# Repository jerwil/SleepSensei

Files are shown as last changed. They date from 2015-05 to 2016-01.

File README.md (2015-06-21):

# The Sleep Sensei

A device to help users fall asleep using calming breathing training.

Sleep Sensei Logo

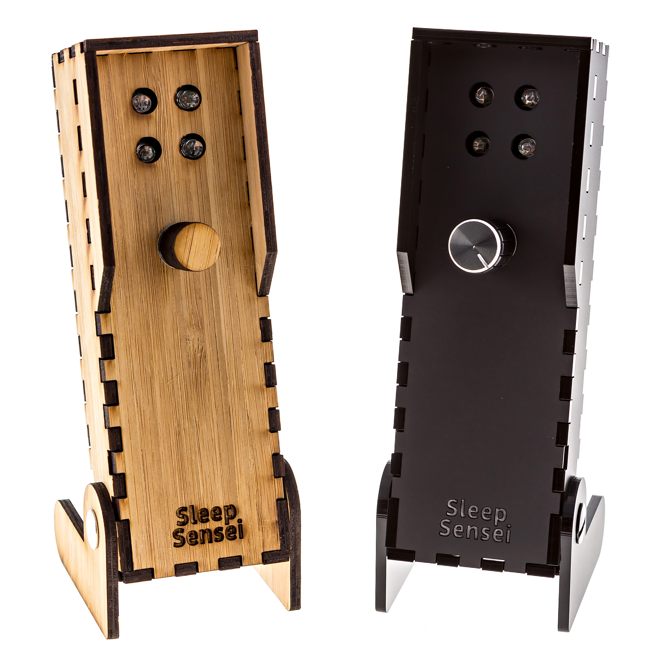
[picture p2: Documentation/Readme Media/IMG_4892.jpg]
Sleep Sensei Photos


## Features

* Creates a pattern of light that you match your breathing to
* Breathing rate is decreased during coaching session, so this helps ease you into sleep faster
* The maximum brightness can be adjusted on-the-fly
* 4 built-in profiles
* The initial breath length, final breath length, and session duration are adjustable for all 4 profiles
* Profile modifications are saved to the device's non-volatile memory
* One-button/knob operation

## How to Use

* Set up the Sleep Sensei on a night stand or table next to your bed.
* Turn on the sleep coach and adjust its angle to either shine in your eyes or on a wall or ceiling.
* Chose a profile and start a sleep coaching session
* Follow the pattern of light with your breathing (brighter = inhale, dimmer = exhale)
* Fall asleep faster!

## Kickstarter

The Sleep Sensei is on Kickstarter!

* [Kickstarter Link](https://www.kickstarter.com/projects/1999114877/the-sleep-sensei)

## Study

I have been conducting a study to collect data on the Sleep Coach to see if it actually helps users fall asleep.

* [Study Information](http://i.imgur.com/wzw9Kvx.jpg)
* [Study Sign-up link] (http://goo.gl/noJXXP)
* [Study Results So Far] (https://github.com/jerwil/SleepCoach/blob/master/Documentation/Data%20Summary%20-%20Round%202.pdf?raw=true)

So far I have had great success with the Sleep Sensei. I'm always looking for more study participants!

## Requirements

### Hardware

* ATtiny85
* 8 pin DIP socket (recommended)
* 220Ω resistor
* 2 10kΩ resistors
* 10 mF capacitor
* 4 red LEDs
* Rotary encoder
* Battery holder for 2 AA batteries
* Body/housing (lasercut design included in repository)

### Schematics

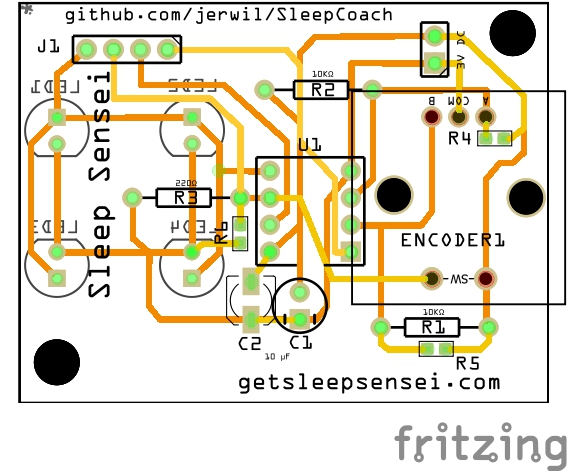
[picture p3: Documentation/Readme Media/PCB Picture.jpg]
Sleep Coach schematic


See the included Fritzing diagram (.fzz file) for details.

### License

<br /><span xmlns:dct="http://purl.org/dc/terms/" property="dct:title">Sleep Sensei</span> by <a xmlns:cc="http://creativecommons.org/ns#" href="http://www.JeremyAdamWilson.com">Jeremy Wilson</a> is licensed under a <a rel="license" href="http://creativecommons.org/licenses/by-nc/4.0/">Creative Commons Attribution-NonCommercial 4.0 International License</a>.

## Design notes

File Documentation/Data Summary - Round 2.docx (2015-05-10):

Sleep Coach Study – Round 2 Results

Study Premise: I created a device to try to help people fall asleep faster. I found several people willing to try the device and provide me data on their sleep via a daily survey and seep tracking smartphone app. I had the users record data for 3 weeks without the sleep coach, and I then sent the users the sleep coach device and had them record data for 3 weeks of sleep using the device.

Device Details: The Arduino-based device produces adjustable high-intensity light that can shine through your eyelids in a sinusoidally increasing and decreasing pattern of brightness with a period that lengthens over time. You match your breathing up with the intensity of the light, and over time your breathing slows.

The big problem I found with similar smartphone apps is that you need to have your eyes open to see the light, and most people do not try to get to sleep with their eyes open. I’ve designed the device to be adjustable to obtain the ideal angle of light from the nightstand to the eyes, and the max brightness is adjustable. The device is in an alpha state, meaning it isn’t pretty, but it gets the job done.

Results

User 1:

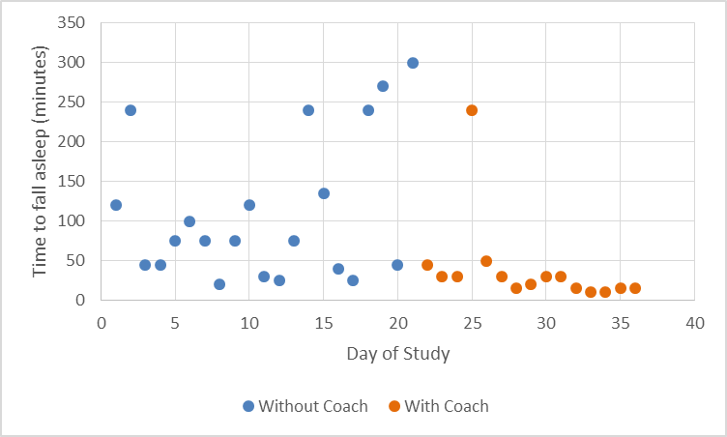
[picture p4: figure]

Average time to sleep without sleep coach: 111 minutes.

Average time to sleep with sleep coach: 39 minutes (25 minutes with outlier removed).

User Thoughts: “I think the quality of sleep has been improving, and I think that's the sleep coach.”

User 2:

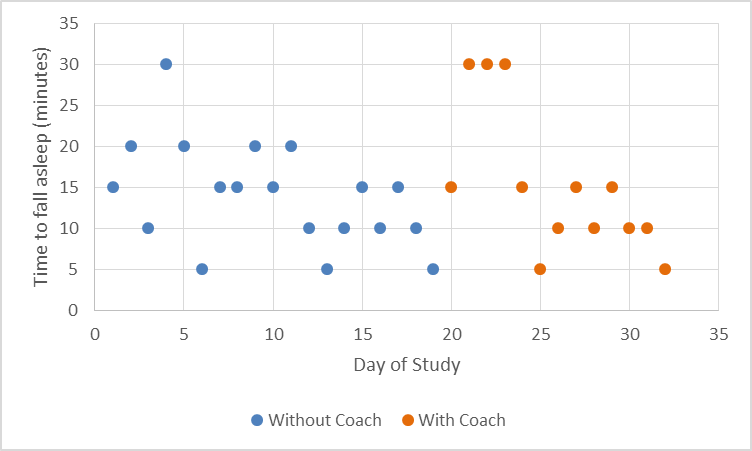
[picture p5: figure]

Average time to sleep without sleep coach: 21 minutes (14 minutes with outlier removed).

Average time to sleep with sleep coach: 15 minutes.

User Thoughts: “I was really impressed with the sleep coach- it cut the amount of time it took me to fall asleep by about half.”

User 3:

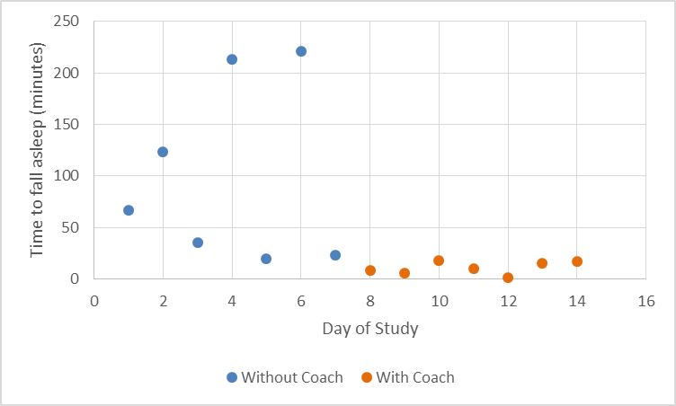
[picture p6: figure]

Average time to sleep without sleep coach: 100 minutes

Average time to sleep with sleep coach: 11 minutes.

Note: this user only provided 2 weeks of data.

New user data as of 5/25/13:

User 4:

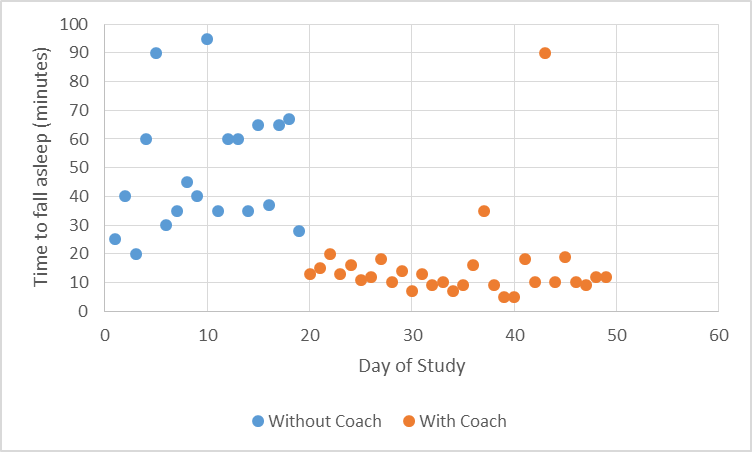
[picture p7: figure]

Average time to sleep without sleep coach: 49 minutes

Average time to sleep with sleep coach: 15 minutes (12 minutes with outlier removed).

User Thoughts: “When I am able to settle down and get in bed at a decent hour, the sleep coach helps immensely in allowing me to fall asleep in an acceptable amount of time. Usually I get incredibly distracted and it can take an hour, sometimes many hours, to fall asleep. The sleep coach allows me to fall asleep in at least under 30 minutes, sometimes even as few as 7 minutes, which is great for me! I would definitely recommend this device to anyone who is on the search for something new to help them fall asleep, someone who perhaps has tried every other sleep aid without finding anything that truly helps yet. The Sleep Coach is awesome!”

User 5:

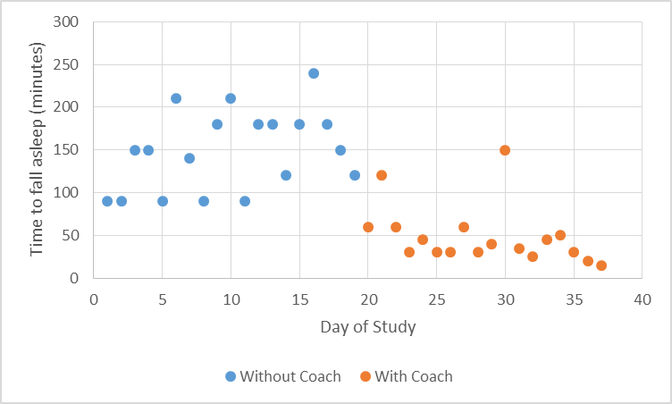
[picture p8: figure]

Average time to sleep without sleep coach: 149 minutes.

Average time to sleep with sleep coach: 49 minutes.

User Thoughts: “I've noticed a HUGE decrease in how long it takes me to fall asleep which has been wonderful! I really like the machine. It's easy to use and works well. I was worried I might not be able to see the light or that if I could it might trigger my migraines, but I can see it with no headaches caused by it. I was also expecting it to be huge for some reason, so I was pleasantly surprised by the compact size.”

User 6:

Average time to sleep without sleep coach: 19.8 minutes.

Average time to sleep with sleep coach: 8.8 minutes.

Conclusion

Similar to the last time I performed the study, actually getting data from volunteers was challenging. This time I sent out 5 sleep coaches and got reasonable data sets from 2 participants, making the total study participant count 5.

User 1 showed great improvement, and I got lots of data from this user so I can say fairly confidently that the sleep coach has improved this user’s time to fall asleep.

User 2 showed little to no improvement from the sleep coach over the 2 weeks of the study, but there is a slight trend showing that time to fall asleep may have been less for the second week indicating that the user may have been getting used to the sleep coach during the first week of use. The user feels as though their sleep has improved greatly.

User 3 showed great improvement, but the data set is quite limited. Since all data is user reported, there is no way to tell if the data is truthful or not.

User 4 showed great improvement and provided the most complete data set. This user reports that they will continue to use the sleep coach to help them fall asleep.

User 5 has had serious problems falling asleep, and the data shows that the sleep coach has helped this person consistently fall asleep faster.

User 6 shows improvement in the regularity of time to fall asleep when using the device. The device also seems to allow this user to fall asleep in under 20 minutes consistently.

Overall, the data is still promising. One thing that I have noticed is that the sleep coach seems to add consistency to participants’ time to fall asleep. Most of the users were all over the place with time to fall asleep before using the coach, and the sleep coach seems to give them a more consistent window of time in which they will fall asleep. I will continue to try to gain study participants. The switch to google forms for the surveys and sleep logs has greatly improved the organization of the study.

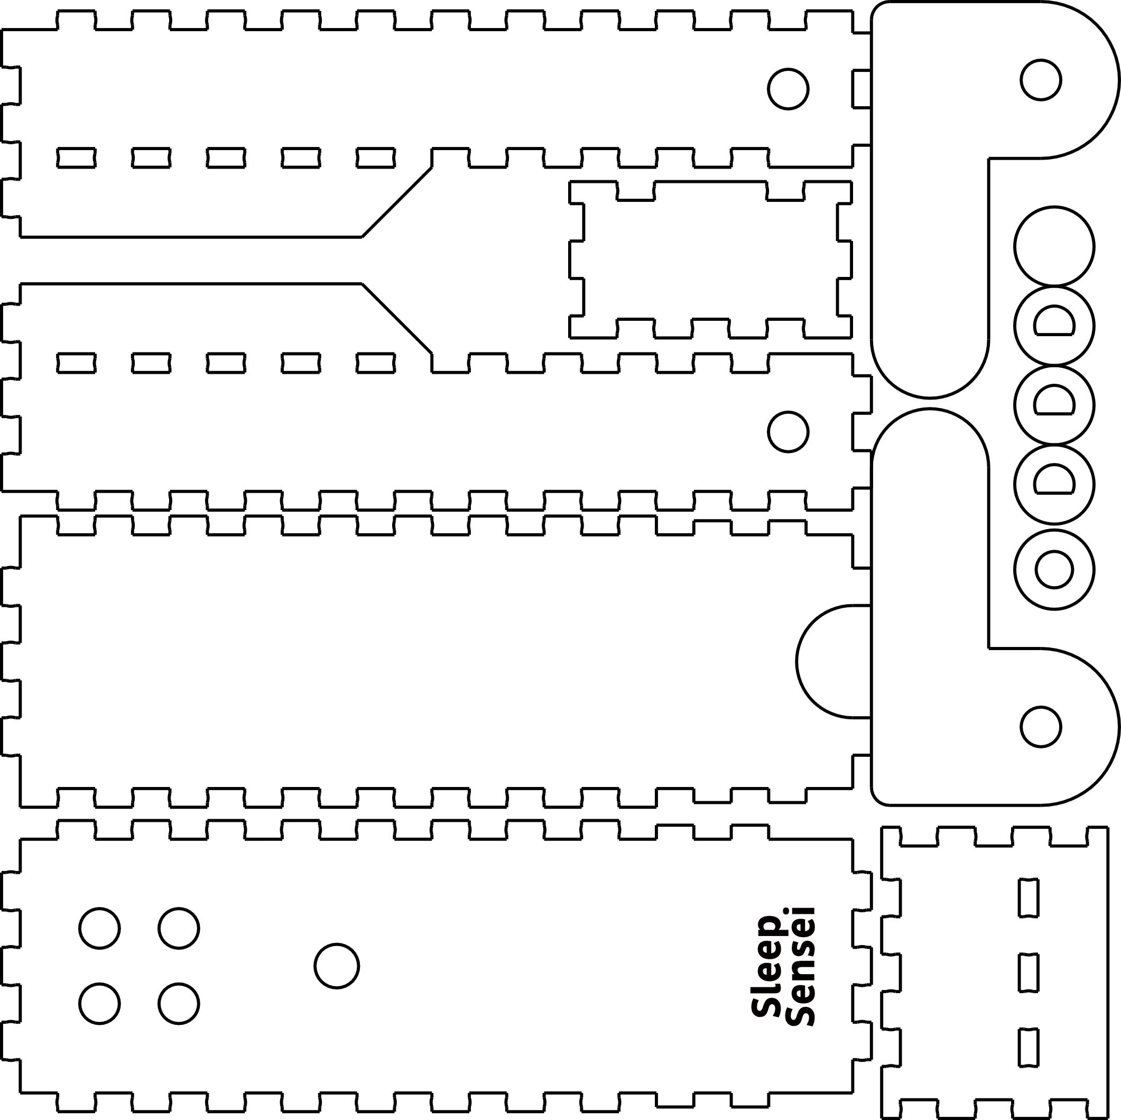
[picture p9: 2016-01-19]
Mechanical Design/g6311.png

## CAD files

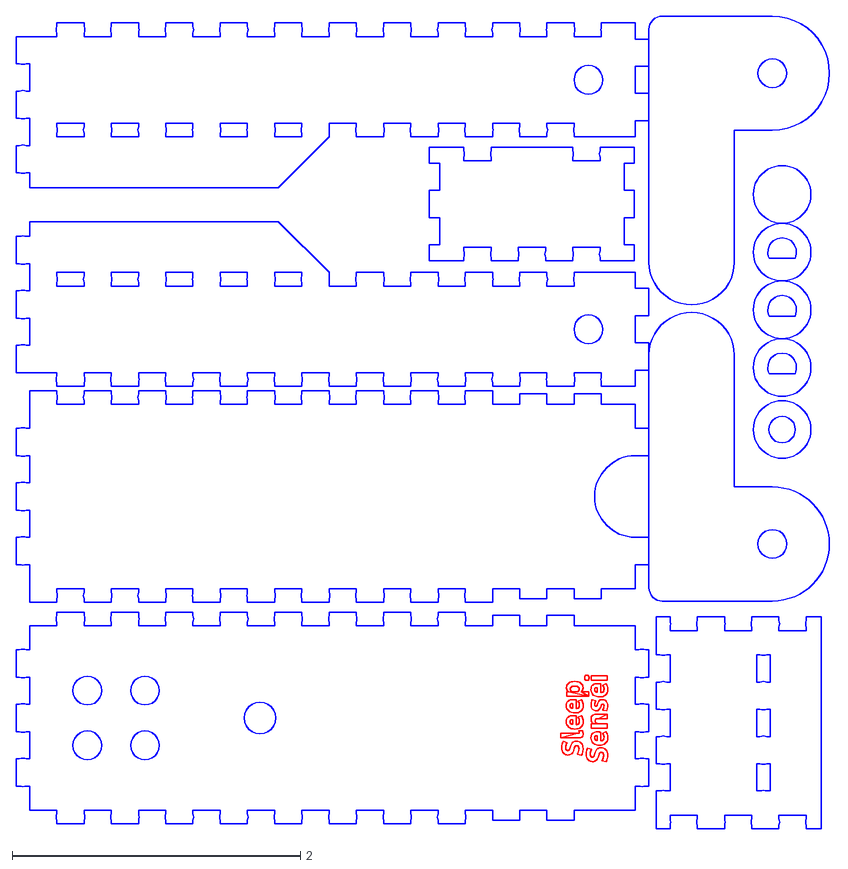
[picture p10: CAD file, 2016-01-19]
Mechanical Design/SleepSensei.dxf
5.66 x 5.63

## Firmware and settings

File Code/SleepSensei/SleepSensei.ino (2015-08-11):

#include <math.h>
#include <EEPROM.h>
#include <avr/sleep.h>

// Sleep Sensei using ATtiny85

//Programming ATtiny85 learned from: http://www.instructables.com/id/Program-an-ATtiny-with-Arduino/step2/Wire-the-circuit/

// Setting up bits for sleep mode (from: http://www.insidegadgets.com/2011/02/05/reduce-attiny-power-consumption-by-sleeping-with-the-watchdog-timer/)

#ifndef cbi
#define cbi(sfr, bit) (_SFR_BYTE(sfr) &= ~_BV(bit))
#endif
#ifndef sbi
#define sbi(sfr, bit) (_SFR_BYTE(sfr) |= _BV(bit))
#endif



char* mode = "initialize"; // Default mode is "initialize"
// Time choose mode is where the user choses between 7, 14, 21, and 28 minutes of sleep coaching
// sleep coach mode is the mode with pulsating light
// off is when the sleep coaching is complete. A button press will bring it into time choose mode
// Intermediate modes are used to indicate switching between modes

int profile = 1;

const int LEDPin = 0;
const int pin_A = 4;  // Rotary Encoder Pin A
const int pin_B = 3;  // Rotary Encoder Pin B
const int ButtonPin = 1;

unsigned char encoder_A;
unsigned char encoder_B;
unsigned char encoder_A_prev=0;

int button_state = 0;
int button_pushed = 0; // This is the indicator that the button was pushed and released
int button_counter = 0; // This is used to detect how long the button is held for

int blink = 1; // This is used for blinking the LEDs
int blink_time = 500;
int blink_value = 254;
int blinks_until_break = 1;

int timeout = 0; // This is the timeout counter
int timeout_setting = 60; // This is the setting for timeout in time_choose mode. If this is exceeded, the device will go to off mode

int brightness_mult = 9;    // how bright the LED is, start at half brightness
int fadeAmount = 1;    // how many points to fade the LED by


unsigned long currentTime;
double milis_timer[1] = {0}; // This is used to keep track of the timer used to tick for each milisecond
double second_timer[1] = {0}; // This is used to keep track of the timer used to tick for each second
double blink_timer[1] = {0};  // This is used to keep track of each half second for blinking
int ticked = 0;

int clockwise = 0;
int counterclockwise = 0;

int delay_int = 1;
int brightness = 0;
int max_brightness = 244;
double brightincrease = 1;
double k = 0.00108*5;
double k_initial = 0.00108*5;
double k_final = 0.00065;
double x = 3*3.14159/2/k; // This starts it at 0 brightness

// K-factors - these are used in the sine wave generation portion to change the period of the sine wave. (a k of .0054 corresponds to 6 second breath, a k of .001 corresponds to an 18 second breath) //

double k_delta = .0002; // The amount of change in k for each rotary encoder tick

double k_values[8] = {.0054, .0054, .0054, .0054, .003, .0025, .0022, .0019}; // {k1_initial, k2_initial, k3_initial, k4_initial, k1_final, k2_final, k3_final, k4_final}

int profile_times_array[4] = {1, 2, 3, 4}; // Each profile is stored as a tens digit. Available options are 10, 20, 30, 40, 50, 60, 70, 80, and 90 minute long sessions

// EEPROM is mapped as follows : {k1_initial, k2_initial, k3_initial, k4_initial, k1_final, k2_final, k3_final, k4_final, Profile 1 duration, Profile 2 duration, Profile 3 duration, Profile 4 duration}
// EEPROM location 25 is used to see if program has written to EEPROM before. It will contain a value of 1 if this program has written to it, indicating that the rest of the EEPROM can be read.

int val = 200; // Current value read from EEPROM

double total_time = 600; // seconds for entire breathing coaching
double current_time = 0;

int button_press_initiate[1];     // storage for button press function
int button_press_completed[1];    // storage for button press function

int tens_digit = 0; // Tens digit used to choose session time
int ones_digit = 7; // Ones digit used to choose session time


void setup() {                
  pinMode(LEDPin, OUTPUT);
  pinMode(ButtonPin, INPUT);
  pinMode(pin_A, INPUT);
  pinMode(pin_B, INPUT);
  
  sbi(GIMSK,PCIE); // Turn on Pin Change interrupt
  sbi(PCMSK,PCINT1); // Which pins are affected by the interrupt
//  Serial.begin(9600); 


}


void loop() {
  
if (mode == "initialize"){
  
if (digitalRead(ButtonPin) == 1){
  eeprom_reset();
  flash_led(LEDPin, 10, 50);
}
 
else if (EEPROM.read(25) == 1){

for (int i = 0; i < 8; i++){
  val = EEPROM.read(i);
  k_values[i] = val;
  k_values[i] = k_values[i]/10000;
}
for (int i = 8; i < 12; i++){
  val = EEPROM.read(i);
  profile_times_array[i-8] = val;
}
}

else {
   eeprom_reset();
}
  
mode = "time_choose";
blinks_until_break = 0;
}
  
    clockwise = 0;
    counterclockwise = 0;
    encoder_A = digitalRead(pin_A);    // Read encoder pins
    encoder_B = digitalRead(pin_B);   
    if((!encoder_A) && (encoder_A_prev)){
      // A has gone from high to low 
      if(encoder_B) {
        // B is high so clockwise
        // increase the brightness multiplier, dont go over 25
        clockwise = 1;            
      }   
      else {
        // B is low so counter-clockwise      
        // decrease the brightness, dont go below 0
         counterclockwise = 1;        
      } 
    }
encoder_A_prev = encoder_A;  
max_brightness = brightness_mult*10;

button_state = digitalRead(ButtonPin);
button_pushed = button_press (button_state, button_press_initiate, button_press_completed);
  
if (mode == "time_choose"){
  
  if (clockwise == 1){if(brightness_mult + fadeAmount <= 25) brightness_mult += fadeAmount;}
  if (counterclockwise == 1){if(brightness_mult - fadeAmount >= 2) brightness_mult -= fadeAmount;}
  
x = 0;
  
//delay(10);

if (button_pushed == 1){
profile += 1;
button_pushed = 0;
blinks_until_break = 0;
}
if (profile > 4){
profile = 0;
blinks_until_break = 0;
tick_reset(blink_timer);
mode = "off";
}
  
//blink_time = blink_times_array[profile-1];
 
if (tick(1000,second_timer) == 1){
timeout += 1;
if (button_state == 1){button_counter += 1;}
//flash_led(LEDPin,profile,150);
}

if (button_state == 0){button_counter = 0;}

if (tick(200,blink_timer) == 1){
 if (blink == 1){
   blink = 0;
 }
 else if (blink == 0){
   blink = 1;   
     if (blinks_until_break == 1){blink = 0;}
     if (blinks_until_break <= 0){
     blink = 0;
     blinks_until_break = profile + 1;
     }
     else {blinks_until_break -= 1;}

 }
}

if (button_state == 1){
timeout = 0;
}

blink_value = max_brightness;

if (blink == 0){  
blink_value = 0;
}

analogWrite(LEDPin, blink_value);


if (button_counter >= 3){ // If the user holds the button for 3 seconds, start the sleep coach
button_pushed = 0;
mode = "sleep_coach";
button_counter = 0;

total_time = (profile_times_array[profile-1]*600);
k_initial = k_values[profile-1];
k_final = k_values[profile+3];

}

if (timeout >= timeout_setting){mode = "off";}
 
//flash_led(LEDPin,profile,250);

 
}
  
if (mode == "sleep_coach"){
  
if (clockwise == 1){if(brightness_mult + fadeAmount <= 25) brightness_mult += fadeAmount;}
if (counterclockwise == 1){if(brightness_mult - fadeAmount >= 2) brightness_mult -= fadeAmount;}
  
timeout = 0;
  
if (current_time >= total_time && brightness <= 10){
current_time = 0;
profile = 0;
mode = "off";
x = 0;
}
  
brightness = max_brightness/2*(1 + sin(k*x));
  
if (tick(delay_int,milis_timer) == 1){
  x += brightincrease;
}
if (tick(1000,second_timer) == 1){
  current_time += 1;
  k = k_initial + current_time*(k_final-k_initial)/total_time;
  if (button_state == 1){button_counter += 1;} 
}
if (x*k >= 2*3.14159){x=0;}
//else if (brightness <= 0){brightincrease = 1;}
  analogWrite(LEDPin,brightness);

if (button_state == 0){button_counter = 0;}

if (button_counter >= 3){ // If the user holds the button for 3 seconds, start the sleep coach
button_pushed = 0;
mode = "to_initial_adjust";
button_counter = 0;
}

if (button_pushed == 1 && current_time > 5){ // Turn the device off by pushing the button, but do not create false press after starting
mode = "off";
button_pushed = 0;
button_counter = 0;
current_time = 0;
profile = 0;
x = 3*3.14159/2/k; // Start it back at 0 brightness
}

}

if (mode == "to_initial_adjust"){
  
  x = 0;
  button_pushed = 0;
  flash_led(LEDPin, 3, 100);
  k = k_values[profile-1];
  mode = "initial_adjust";

}

if (mode == "initial_adjust"){

// Adjusts the initial breath length of the currently selected profile
  
if (counterclockwise == 1)
  {if(k + k_delta <= .01) 
    {k += k_delta;
    timeout = 0;}
  }
else if (clockwise == 1)
  {if(k - k_delta >= .0019) 
    {k -= k_delta;
    timeout = 0;}
  }
brightness = 127*(1 + sin(k*x));  
if (tick(delay_int,second_timer) == 1){
  x += brightincrease;
}

if (x*k >= 2*3.14159){x=0;}

analogWrite(LEDPin,brightness);

if (tick(1000,blink_timer) == 1){
timeout += 1;
if (button_state == 1){button_counter += 1;}
}

if (button_state == 0){button_counter = 0;}

if (button_counter >= 3){ // If the user holds the button for 3 seconds, go to mode to adjust final breath length
button_pushed = 0;
mode = "to_final_adjust";
button_counter = 0;
timeout = 0;
}

if (button_state == 1){
timeout = 0;
}

if (timeout >= timeout_setting){
mode = "off";
timeout = 0;
}

}

if (mode == "to_final_adjust"){
  
x = 0;
k_values[profile-1] = k;
val = k*10000;
EEPROM.write(profile-1,val);
EEPROM.write(25, 1);  
flash_led(LEDPin, 5, 100);
mode = "final_adjust";
k = k_values[profile+3];

}


if (mode == "final_adjust"){

// Adjusts the final breath length of the currently selected profile
  
if (counterclockwise == 1)
  {if(k + k_delta <= .01) 
    {k += k_delta;
    timeout = 0;}
  }
else if (clockwise == 1)
  {if(k - k_delta >= .0019) 
    {k -= k_delta;
    timeout = 0;}
  }

brightness = 127*(1 + sin(k*x));  
if (tick(delay_int,second_timer) == 1){
  x += brightincrease;
}

if (x*k >= 2*3.14159){x=0;}

analogWrite(LEDPin,brightness);


if (tick(1000,blink_timer) == 1){
timeout += 1;
if (button_state == 1){button_counter += 1;}
}

if (button_state == 0){button_counter = 0;}

if (button_counter >= 3){ // If the user holds the button for 3 seconds, go to adjust tens digit of duration
button_pushed = 0;
mode = "to_tens_digit_adjust";
button_counter = 0;
timeout = 0;

k_values[profile+3] = k;
val = k*10000;
EEPROM.write(profile+3,val);
EEPROM.write(25, 1);

}

if (button_state == 1){
timeout = 0;
}

if (timeout >= timeout_setting){
mode = "off";
timeout = 0;
}

}

if (mode == "to_tens_digit_adjust"){
tens_digit = profile_times_array[profile-1];
mode = "tens_digit_adjust";
blinks_until_break = tens_digit + 1;
for (int n=0; n < 3; n++) {pulse_led(LEDPin, 1);}
}

if (mode == "tens_digit_adjust"){
  
if (tick(1000,second_timer) == 1){
timeout += 1;
if (button_state == 1){button_counter += 1;}
}

if (button_state == 0){button_counter = 0;}
  
if (counterclockwise == 1)
  {if(tens_digit > 1) 
    {tens_digit -= 1;
     timeout = 0;}
  }
else if (clockwise == 1)
  {if(tens_digit < 9) 
    {tens_digit += 1;
     timeout = 0;}
  }

//if (button_pushed == 1 && tens_digit > 0){flash_led(LEDPin, tens_digit, 200);}

if (tick(200,blink_timer) == 1){
 if (blink == 1){
   blink = 0;
 }
 else if (blink == 0){
   blink = 1;   
     if (blinks_until_break == 1){blink = 0;}
     if (blinks_until_break <= 0){
     blink = 0;
     blinks_until_break = tens_digit + 1;
     }
     else {blinks_until_break -= 1;}

 }
}

blink_value = max_brightness;

if (blink == 0){  
blink_value = 0;
}

analogWrite(LEDPin, blink_value);

if (timeout >= timeout_setting){
mode = "off";
timeout = 0;
}

if (button_counter >= 3){ // If the user holds the button for 3 seconds, go to adjust ones digit of duration
button_pushed = 0;
mode = "back_to_menu";
button_counter = 0;
timeout = 0;
blinks_until_break = profile + 1;

profile_times_array[profile-1] = tens_digit;
EEPROM.write(profile+7,tens_digit);
EEPROM.write(25, 1);

}

}

if (mode == "back_to_menu"){
  
x = 0;  
for (int n=0; n < 5; n++) {pulse_led(LEDPin, 1);}
button_pushed = 0;
button_counter = 0;
mode = "time_choose";
profile -= 1;

}

if (mode == "off"){
  
x = 0;

analogWrite(LEDPin,  0);  
  
system_sleep();
  
delay(1);

if (button_state == 1){ // Turn the device on by pushing the button
mode = "time_choose";
button_pushed = 0;
button_counter = 0;
timeout = 0;
profile = 0;
}

current_time = 0;
blinks_until_break = 0;
  
}

}

int button_press (int button_indicator, int button_press_initiated[1], int button_press_complete[1]){
	if (button_indicator == 0 && button_press_initiated[0] == 1) {
	button_press_complete[0] = 1;
	button_press_initiated[0] = 0;
	}
	else if (button_indicator == 1){
	button_press_initiated[0] = 1;
	button_press_complete[0] = 0;
	}
	else {button_press_complete[0] = 0;}
return button_press_complete[0];
}

int tick(int delay, double timekeeper[1]){
currentTime = millis();
if(currentTime >= (timekeeper[0] + delay)){
	timekeeper[0] = currentTime;
	return 1;
  }
else {return 0;}
}

void tick_reset(double timekeeper[1]){
currentTime = millis();
timekeeper[0] = currentTime;
}

void flash_led(int pin, int times_to_flash, int wait_time){
  int i = 1;
  while (i <= times_to_flash){
  analogWrite(pin,244);
  delay(wait_time);               
  analogWrite(pin,0);
  delay(wait_time);
  i++;
  }
}

void pulse_led(int pin, int wait_time){
  int i = 1;
  while (i <= 255){
  analogWrite(pin,i);
  delay(wait_time);               
  i++;
  }
  while (i >= 0){
  analogWrite(pin,i);
  delay(wait_time);               
  i--;
  }
}


void eeprom_reset(){
  for (int i = 0; i < 512; i++)
  EEPROM.write(i, 0);
  for (int i = 0; i < 8; i++){
  EEPROM.write(i,k_values[i]*10000);
  }
  for (int i = 8; i < 12; i++){
  EEPROM.write(i,profile_times_array[i-8]);
  }
  EEPROM.write(25,1); 
}

void system_sleep() {
  profile = 0;
  cbi(ADCSRA,ADEN); // Switch Analog to Digital converter OFF
  set_sleep_mode(SLEEP_MODE_PWR_DOWN); // Set sleep mode
  sleep_mode(); // System sleeps here
  sbi(ADCSRA,ADEN);  // Switch Analog to Digital converter ON
}

ISR(PCINT0_vect) {
}

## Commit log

2015-05-10 Added PCB, documents, and mechanical design
    [Complete Data Users 1-5.xlsx, Sleep_Sensei_PCB.fzz, Time Reduction Bargraphs.xlsx]
2015-05-13 Fixed EEPROM rest bug
    EEPROM reset would write raw k values rather than writing k*10000 to get
    them to be integers for EEPROM storage.
    [SleepSensei.ino]
2015-08-11 Made Sleep Sensei return to profile 1 when sleeping
    Also added final lasercutting files used in order
2015-08-11 Fixed menu bug
    Sensei no longer blinks twice on first boot. It will only blink once
    during profile selection menu
    [SleepSensei.ino]
2016-01-19 Created SMD design for mass production
    [SleepSensei.dxf, Sleep_Sensei_SMD.fzz]
